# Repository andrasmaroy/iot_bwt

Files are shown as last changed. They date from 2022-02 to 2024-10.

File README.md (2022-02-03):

# iot_bwt

ESP32 based IoT device to monitor usage of a BWT water filter and report it to Home Assistant via MQTT with TLS and authentication.

## Components

This code is running on a [FireBeetle ESP32 v4.0](https://www.dfrobot.com/product-1590.html) and is connected to a YF-S201 flow sensor along with a no-name 1100mAh LiPo battery. Connect the pins of YF-S201 like this: red - 3.3V, black - GND, yellow - `D2`/`IO25`on the FireBeetle board and use the JST PH 2-Pin battery terminal already on the board for the battery.

On the FireBeetle to get battery monitoring on pin A0 to work R10 and R11 need to be shorted (these are 0R resistors in the schematic). Reference and schematic: https://www.dfrobot.com/forum/viewtopic.php?t=19292

Flashing the FireBeetle with Arduino IDE: set upload speed to 921600 and flash frequency to 80MHz.

## Dependencies

* [ESP32 board definitions](https://github.com/espressif/arduino-esp32/blob/master/docs/arduino-ide/boards_manager.md)
* [ArduinoJson](https://arduinojson.org/)
* [PubSubClient](https://github.com/knolleary/pubsubclient/)
* [ulpcc](https://github.com/jasonful/lcc)
* [ezTime](https://github.com/ropg/ezTime)

## Configuration

All relevant configuration values are in [config.h](config.h), fill in the necessary values to get the project working.

To be able to use secure MQTT connections the appropriate CA has to be added. The one in the code is Let's Encrypt's cross-signed intermediate CA, any pem format CA should work.
**Disclaimer:** I've only got this working got this working with directly the signing certificate, not with a complete certificate chain.

### Home Assistant

The way the code communicates with Home Assistant assumes that [MQTT Discovery](https://www.home-assistant.io/docs/mqtt/discovery/) is enabled and presents as two sensors to be used with a [Utility Meter](https://www.home-assistant.io/integrations/utility_meter/). See example of relevant configuration in [home-assistant.yaml](home-assistant.yaml)

## Acknowledgments

* Espessif's [ULP Pulse Counting Example](https://github.com/espressif/esp-idf/tree/master/examples/system/ulp)
* [C version](https://github.com/jasonful/lcc/blob/master/ulpcc/examples/pulse_cnt.c) of the above courtesy of [ulpcc](https://github.com/jasonful/lcc)

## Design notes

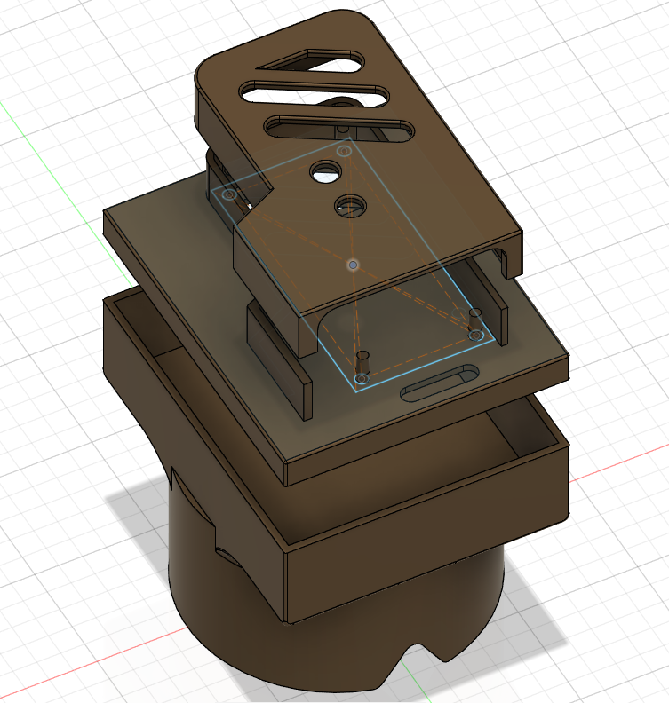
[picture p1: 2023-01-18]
case/Final.png

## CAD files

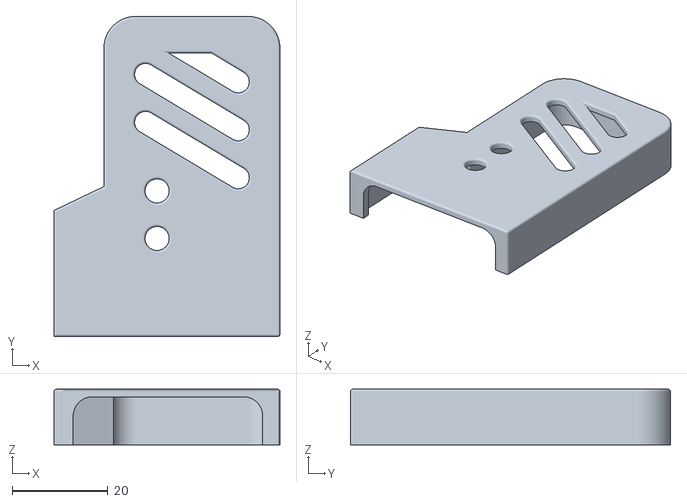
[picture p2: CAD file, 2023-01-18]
case/Controler top.stl
47.1 x 66.7 x 11.6

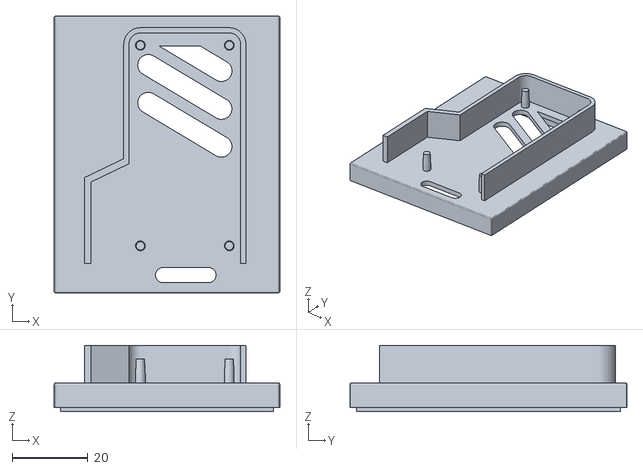
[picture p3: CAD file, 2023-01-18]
case/Battery top.stl
59.7 x 73.2 x 17.5

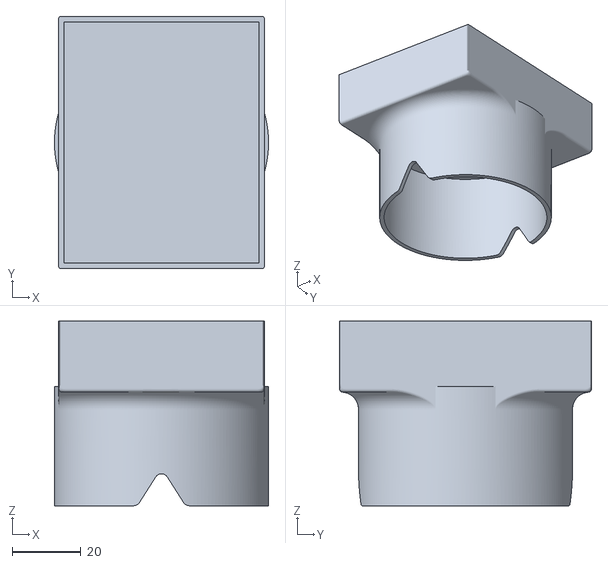
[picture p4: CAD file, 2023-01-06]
case/Base.stl
62.2 x 73.2 x 53.6

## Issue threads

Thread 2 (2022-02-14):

Design enclosure

andrasmaroy, 2022-02-14:
Should fit on top of the BWT filter (while still allowing a wall mount) and provides a firm connection for the flow sensor connector and exposes the USB port for charging.

Closed 2023-01-06.

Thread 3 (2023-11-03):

Report battery percentage while charging

andrasmaroy, 2023-11-03:
When charging the battery the current charge percentage should be reported actively since power is available. Reporting only the battery percentage without flow usage should work with Home Assistant, but needs testing. Otherwise reporting 0 should be fine.

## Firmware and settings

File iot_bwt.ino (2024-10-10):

#include <ArduinoJson.h>
#include <ezTime.h>
#include <PubSubClient.h>
#include <WiFiClientSecure.h>

#include <driver/rtc_io.h>
#include <esp32/ulp.h>
#include <nvs.h>
#include <nvs_flash.h>
#include <ulptool.h>

#include "config.h"
#include "ulp_main.h"

#define uS_TO_S_FACTOR 1000000ULL

extern const uint8_t ulp_main_bin_start[] asm("_binary_ulp_main_bin_start");
extern const uint8_t ulp_main_bin_end[]   asm("_binary_ulp_main_bin_end");

static void init_ulp_program(void);
static void update_pulse_count(void);

WiFiClientSecure wifiClient;
PubSubClient mqttClient(MQTT_URL, MQTT_PORT, wifiClient);

bool publish_config(const String& topic, const byte* bytes, size_t len) {
    Serial.print("Publishing message to '");
    Serial.print(topic);
    Serial.println("'");

    if (! mqttClient.beginPublish(topic.c_str(), len, true)) {
        Serial.println("Error beginning publish");
        return false;
    }
    if (len != mqttClient.write(bytes, len)) {
        Serial.println("Mismatch in written message length!");
        return false;
    }
    if (! mqttClient.endPublish()) {
        Serial.println("Error ending publish");
        return false;
    }
    return true;
}

bool publish_message(const String& topic, const String& msg) {
    Serial.print("Publishing message to '");
    Serial.print(topic);
    Serial.println("'");

    bool res = mqttClient.publish(topic.c_str(), msg.c_str(), true);
    for (uint8_t retries = 0; retries < MAX_RETRY_COUNT && ! res; retries++) {
        Serial.println("Error publishing message");
        Serial.println(" try again in 5 seconds");
        delay(RETRY_DELAY);
        res = mqttClient.publish(topic.c_str(), msg.c_str(), true);
    }
    return res;
}

bool announce_device() {
    Serial.println("Announcing devices");
    StaticJsonDocument<400> configuration;
    byte configBytes[400];
    size_t msgLen;
    uint8_t retries;

    // Flow sensor
    configuration["name"] = "BWT - Water";
    configuration["unit_of_measurement"] = "L";
    configuration["unique_id"] = "bwtwatersensor1";
    configuration["expire_after"] = 90000; // 25 hours
    configuration["state_topic"] = HASS_TOPIC_BASE + "/state";
    configuration["value_template"] = "{{ value_json.water}}";

    msgLen = measureJson(configuration);
    serializeJson(configuration, configBytes, msgLen + 1);

    bool res = publish_config(HASS_TOPIC_BASE + "W/config", configBytes, msgLen);
    for (uint8_t retries = 0; retries < MAX_RETRY_COUNT && ! res; retries++) {
        Serial.println(" try again in 5 seconds");
        delay(RETRY_DELAY);
        res = publish_config(HASS_TOPIC_BASE + "W/config", configBytes, msgLen);
    }
    if (!res) {
        return false;
    }
    serializeJsonPretty(configuration, Serial);
    Serial.println();

    // Battery sensor
    configuration["device_class"] = "battery";
    configuration["name"] = "BWT - Battery Level";
    configuration["unit_of_measurement"] = "%";
    configuration["unique_id"] = "bwtbatsensor1";
    configuration["expire_after"] = 172800; // 2 days
    configuration["state_topic"] = HASS_TOPIC_BASE + "/state";
    configuration["value_template"] = "{{ value_json.battery }}";

    msgLen = measureJson(configuration);
    serializeJson(configuration, configBytes, msgLen + 1);
    res = publish_config(HASS_TOPIC_BASE + "B/config", configBytes, msgLen);
    for (uint8_t retries = 0; retries < MAX_RETRY_COUNT && ! res; retries++) {
        Serial.println(" try again in 5 seconds");
        delay(RETRY_DELAY);
        res = publish_config(HASS_TOPIC_BASE + "B/config", configBytes, msgLen);
    }
    if (!res) {
        return false;
    }
    serializeJsonPretty(configuration, Serial);
    Serial.println();
    return true;
}

void sleep() {
    time_t wakeup_time = WAKEUP_FALLBACK;
    // Get time from NTP to calculate next wakeup time
    if (waitForSync(RETRY_DELAY)) {
      Timezone tz;
      tz.setPosix(TIMEZONE);
      wakeup_time = makeTime(WAKEUP_HOUR, WAKEUP_MINUTE, 0, tz.day() + 1, tz.month(), tz.year()) - tz.now();
    }

    Serial.println("Entering deep sleep\n\n");
    ESP_ERROR_CHECK(esp_sleep_enable_timer_wakeup(wakeup_time * uS_TO_S_FACTOR));
    esp_deep_sleep_start();
}

void setup() {
    //Initialize serial and wait for port to open:
    Serial.begin(115200);
    delay(100);

    esp_sleep_wakeup_cause_t cause = esp_sleep_get_wakeup_cause();
    if (cause != ESP_SLEEP_WAKEUP_TIMER) {
        printf("Not timed wakeup, initializing ULP\n");
        init_ulp_program();
    } else {
        printf("ULP wakeup, saving pulse count\n");
        update_pulse_count();
        Serial.print("Attempting to connect to SSID: ");
        Serial.println(WIFI_SSID);
        WiFi.begin(WIFI_SSID, WIFI_PSK);

        // attempt to connect to Wifi network:
        bool res = WiFi.status() == WL_CONNECTED;
        for (uint8_t retries = 0; retries < MAX_RETRY_COUNT && ! res; retries++) {
            Serial.print(".");
            delay(RETRY_DELAY);
            res = WiFi.status() == WL_CONNECTED;
        }
        if (!res) {
            Serial.println("WiFi connection failed, sleeping");
            sleep();
        }

        Serial.print("Connected to ");
        Serial.println(WIFI_SSID);
        Serial.print("IP address: ");
        Serial.println(WiFi.localIP());

        wifiClient.setCACert(ISRG_Root_X1);

        res = mqttClient.connected();
        for (uint8_t retries = 0; retries < MAX_RETRY_COUNT && ! res; retries++) {
            Serial.print("Attempting MQTT connection...");
            if (mqttClient.connect("iot_bwt", MQTT_USER, MQTT_PASSWORD)) {
                Serial.println("connected");
            } else {
                Serial.print("failed, rc=");
                Serial.print(mqttClient.state());
                Serial.println(" try again in 5 seconds");
                // Wait 5 seconds before retrying
                delay(RETRY_DELAY);
            }
            res = mqttClient.connected();
        }
        if (!res) {
            Serial.println("MQTT connection failed, sleeping");
            sleep();
        }

        if (!announce_device()) {
            Serial.println("Announcing devices failed, sleeping");
            sleep();
        }

        StaticJsonDocument<46> state;
        String stateStr;

        /*
         * Workaround Home Assistant' utility meter behaviour
         * It expects a monotonically increasing value and cumulates the
         * difference for each submission. To trick this into adding all the
         * submitted values straight up, we can send a 0 value before sending
         * the real one, this way the difference is always compared to 0, so
         * the correct value gets added.
         */
        state["battery"] = (uint8_t)((float)(analogRead(A0) - BATTERY_MIN) / (BATTERY_MAX - BATTERY_MIN) * 100);
        if (state["battery"] > 100) state["battery"] = 100;
        state["water"] = 0;
        stateStr = "";
        serializeJson(state, stateStr);
        res = publish_message(HASS_TOPIC_BASE + "/state", stateStr);
        serializeJsonPretty(state, Serial);
        Serial.println();

        if (res) {
            // Publish actual usage second
            const char* namespc = "pulsecnt";
            const char* count_key = "count";

            ESP_ERROR_CHECK( nvs_flash_init() );
            nvs_handle handle;
            ESP_ERROR_CHECK( nvs_open(namespc, NVS_READWRITE, &handle));
            uint32_t pulse_count = 0;
            esp_err_t err = nvs_get_u32(handle, count_key, &pulse_count);
            assert(err == ESP_OK || err == ESP_ERR_NVS_NOT_FOUND);

            state["water"] = (float)pulse_count / 400;
            stateStr = "";
            serializeJson(state, stateStr);
            if (publish_message(HASS_TOPIC_BASE + "/state", stateStr)) {
                ESP_ERROR_CHECK(nvs_set_u32(handle, count_key, 0));
                ESP_ERROR_CHECK(nvs_commit(handle));
            }
            serializeJsonPretty(state, Serial);
            Serial.println();

            nvs_close(handle);

            // Publish 0 usage again so that retained messages don't result in
            // false data when picked up.
            state["water"] = 0;
            stateStr = "";
            serializeJson(state, stateStr);
            res = publish_message(HASS_TOPIC_BASE + "/state", stateStr);
            serializeJsonPretty(state, Serial);
            Serial.println();
        }
    }

    sleep();
}

static void init_ulp_program(void) {
    esp_err_t err = ulp_load_binary(0, ulp_main_bin_start,
            (ulp_main_bin_end - ulp_main_bin_start) / sizeof(uint32_t));
    ESP_ERROR_CHECK(err);

    /* GPIO used for pulse counting. */
    gpio_num_t gpio_num = PIN_FLOW_SENSOR;
    int rtcio_num = PIN_RTC;
    assert(rtc_gpio_is_valid_gpio(gpio_num) && "GPIO used for pulse counting must be an RTC IO");

    /*
     * Initialize some variables used by ULP program.
     * Each 'ulp_xyz' variable corresponds to 'xyz' variable in the ULP program.
     * These variables are declared in an auto generated header file,
     * 'ulp_main.h', name of this file is defined in component.mk as ULP_APP_NAME.
     * These variables are located in RTC_SLOW_MEM and can be accessed both by the
     * ULP and the main CPUs.
     *
     * Note that the ULP reads only the lower 16 bits of these variables.
     */
    ulp_debounce_counter = 3;
    ulp_debounce_max_count = 3;
    ulp_next_edge = 0;
    ulp_io_number = rtcio_num; /* map from GPIO# to RTC_IO# */
    // ulp_edge_count_to_wake_up = 200;

    /* Initialize selected GPIO as RTC IO, enable input, disable pullup and pulldown */
    rtc_gpio_init(gpio_num);
    rtc_gpio_set_direction(gpio_num, RTC_GPIO_MODE_INPUT_ONLY);
    // rtc_gpio_pulldown_dis(gpio_num);
    rtc_gpio_pullup_dis(gpio_num);
    rtc_gpio_hold_en(gpio_num);

    /*
     * Disconnect GPIO12 and GPIO15 to remove current drain through
     * pullup/pulldown resistors.
     * GPIO12 may be pulled high to select flash voltage.
     */
    rtc_gpio_isolate(GPIO_NUM_12);
    rtc_gpio_isolate(GPIO_NUM_15);
    esp_deep_sleep_disable_rom_logging(); // suppress boot messages

    /*
     * Set ULP wake up period
     * Minimum pulse width has to be T * (ulp_debounce_counter + 1)
     * Maximum flow rate is about 6 L/min which corresponds to 50Hz
     * To be on the safe side consider double that
     * That means a wake up period that is able to detect 10ms pulses
     */
    ulp_set_wakeup_period(0, 10.0 / (ulp_debounce_counter + 1) * 1000);

    /* Start the program */
    err = ulp_run(&ulp_entry - RTC_SLOW_MEM);
    ESP_ERROR_CHECK(err);
}

static void update_pulse_count(void) {
    const char* namespc = "pulsecnt";
    const char* count_key = "count";

    ESP_ERROR_CHECK(nvs_flash_init());
    nvs_handle handle;
    ESP_ERROR_CHECK(nvs_open(namespc, NVS_READWRITE, &handle));
    uint32_t pulse_count = 0;
    esp_err_t err = nvs_get_u32(handle, count_key, &pulse_count);
    assert(err == ESP_OK || err == ESP_ERR_NVS_NOT_FOUND);
    printf("Read pulse count from NVS: %5d\n", pulse_count);

    /* ULP program counts signal edges, convert that to the number of pulses */
    uint32_t pulse_count_from_ulp = (ulp_edge_count & UINT16_MAX) / 2;
    /* In case of an odd number of edges, keep one until next time */
    ulp_edge_count = ulp_edge_count % 2;
    printf("Pulse count from ULP: %5d\n", pulse_count_from_ulp);

    /* Save the new pulse count to NVS */
    pulse_count += pulse_count_from_ulp;
    ESP_ERROR_CHECK(nvs_set_u32(handle, count_key, pulse_count));
    ESP_ERROR_CHECK(nvs_commit(handle));
    nvs_close(handle);
    printf("Wrote updated pulse count to NVS: %5d\n", pulse_count);
}

void loop() { }

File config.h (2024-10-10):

#ifndef CONFIG_H
#define CONFIG_H

// WiFi
#define WIFI_SSID ""
#define WIFI_PSK  ""

// MQTT
#define MQTT_URL      ""
#define MQTT_PORT     1883
#define MQTT_DEV      ""
#define MQTT_USER     ""
#define MQTT_PASSWORD ""

// Battery
#define BATTERY_MIN 1740
#define BATTERY_MAX 2320

// Flow sensor
#define FLOW_PULSE_PER_LITER 400
#define PIN_FLOW_SENSOR      GPIO_NUM_25
#define PIN_RTC              6  // RTC Pin number corresponding to GPIO 25

#define MAX_RETRY_COUNT 5
#define RETRY_DELAY 5000

#define WAKEUP_HOUR     23
#define WAKEUP_MINUTE   55
#define WAKEUP_FALLBACK 86400 // 1 day as fallback

#define TIMEZONE "CET-1CEST,M3.5.0,M10.5.0/3" // Europe/Budapest


const char* ISRG_Root_X1 = \
    "-----BEGIN CERTIFICATE-----\n" \
    "MIIFazCCA1OgAwIBAgIRAIIQz7DSQONZRGPgu2OCiwAwDQYJKoZIhvcNAQELBQAw\n" \
    "TzELMAkGA1UEBhMCVVMxKTAnBgNVBAoTIEludGVybmV0IFNlY3VyaXR5IFJlc2Vh\n" \
    "cmNoIEdyb3VwMRUwEwYDVQQDEwxJU1JHIFJvb3QgWDEwHhcNMTUwNjA0MTEwNDM4\n" \
    "WhcNMzUwNjA0MTEwNDM4WjBPMQswCQYDVQQGEwJVUzEpMCcGA1UEChMgSW50ZXJu\n" \
    "ZXQgU2VjdXJpdHkgUmVzZWFyY2ggR3JvdXAxFTATBgNVBAMTDElTUkcgUm9vdCBY\n" \
    "MTCCAiIwDQYJKoZIhvcNAQEBBQADggIPADCCAgoCggIBAK3oJHP0FDfzm54rVygc\n" \
    "h77ct984kIxuPOZXoHj3dcKi/vVqbvYATyjb3miGbESTtrFj/RQSa78f0uoxmyF+\n" \
    "0TM8ukj13Xnfs7j/EvEhmkvBioZxaUpmZmyPfjxwv60pIgbz5MDmgK7iS4+3mX6U\n" \
    "A5/TR5d8mUgjU+g4rk8Kb4Mu0UlXjIB0ttov0DiNewNwIRt18jA8+o+u3dpjq+sW\n" \
    "T8KOEUt+zwvo/7V3LvSye0rgTBIlDHCNAymg4VMk7BPZ7hm/ELNKjD+Jo2FR3qyH\n" \
    "B5T0Y3HsLuJvW5iB4YlcNHlsdu87kGJ55tukmi8mxdAQ4Q7e2RCOFvu396j3x+UC\n" \
    "B5iPNgiV5+I3lg02dZ77DnKxHZu8A/lJBdiB3QW0KtZB6awBdpUKD9jf1b0SHzUv\n" \
    "KBds0pjBqAlkd25HN7rOrFleaJ1/ctaJxQZBKT5ZPt0m9STJEadao0xAH0ahmbWn\n" \
    "OlFuhjuefXKnEgV4We0+UXgVCwOPjdAvBbI+e0ocS3MFEvzG6uBQE3xDk3SzynTn\n" \
    "jh8BCNAw1FtxNrQHusEwMFxIt4I7mKZ9YIqioymCzLq9gwQbooMDQaHWBfEbwrbw\n" \
    "qHyGO0aoSCqI3Haadr8faqU9GY/rOPNk3sgrDQoo//fb4hVC1CLQJ13hef4Y53CI\n" \
    "rU7m2Ys6xt0nUW7/vGT1M0NPAgMBAAGjQjBAMA4GA1UdDwEB/wQEAwIBBjAPBgNV\n" \
    "HRMBAf8EBTADAQH/MB0GA1UdDgQWBBR5tFnme7bl5AFzgAiIyBpY9umbbjANBgkq\n" \
    "hkiG9w0BAQsFAAOCAgEAVR9YqbyyqFDQDLHYGmkgJykIrGF1XIpu+ILlaS/V9lZL\n" \
    "ubhzEFnTIZd+50xx+7LSYK05qAvqFyFWhfFQDlnrzuBZ6brJFe+GnY+EgPbk6ZGQ\n" \
    "3BebYhtF8GaV0nxvwuo77x/Py9auJ/GpsMiu/X1+mvoiBOv/2X/qkSsisRcOj/KK\n" \
    "NFtY2PwByVS5uCbMiogziUwthDyC3+6WVwW6LLv3xLfHTjuCvjHIInNzktHCgKQ5\n" \
    "ORAzI4JMPJ+GslWYHb4phowim57iaztXOoJwTdwJx4nLCgdNbOhdjsnvzqvHu7Ur\n" \
    "TkXWStAmzOVyyghqpZXjFaH3pO3JLF+l+/+sKAIuvtd7u+Nxe5AW0wdeRlN8NwdC\n" \
    "jNPElpzVmbUq4JUagEiuTDkHzsxHpFKVK7q4+63SM1N95R1NbdWhscdCb+ZAJzVc\n" \
    "oyi3B43njTOQ5yOf+1CceWxG1bQVs5ZufpsMljq4Ui0/1lvh+wjChP4kqKOJ2qxq\n" \
    "4RgqsahDYVvTH9w7jXbyLeiNdd8XM2w9U/t7y0Ff/9yi0GE44Za4rF2LN9d11TPA\n" \
    "mRGunUHBcnWEvgJBQl9nJEiU0Zsnvgc/ubhPgXRR4Xq37Z0j4r7g1SgEEzwxA57d\n" \
    "emyPxgcYxn/eR44/KJ4EBs+lVDR3veyJm+kXQ99b21/+jh5Xos1AnX5iItreGCc=\n" \
    "-----END CERTIFICATE-----\n";

#endif  // CONFIG_H

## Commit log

2020-10-18 Add details about battery level monitoring
2020-10-31 Expire device after 25 hours instead of 2 days
2020-10-31 Fine tune battery measurements
2020-11-15 More battery value tuning
2021-04-09 Update readme with wiring details
2021-08-05 Remove availability topic from device configuration
2021-08-05 Retain MQTT messages
    Setting the retain flag for these messages is important, because when
    Home Assistant starts the device is missing, since it is from MQTT
    discovery[1]. If the message is retained then when Home Assistant
    subscribes again to the discovery topic it will receive the device
    configuration and registers it again correctly.
    [1] https://www.home-assistant.io/docs/mqtt/discovery/
    [iot_bwt.ino]
2021-09-03 Clamp battery percentage to 100
    If the voltage is read from the pin while charing the battery, then the calculated percentage might go over 100%. Because of this if should be clamped to the max value
2021-09-29 Send 0L usage after successfully publishing the actual usage
    Since messages are retained the last message in the state topic will
    contain the actual usage. This when combined with Home Assistant
    restarting the next day before the actual usage of the coming day
    published to set the usage for the day incorrectly to the same value as
    the day before.
    Publishing 0 after the actual usage won't change the calculation as for
    that a 0 value is already needed.
    [iot_bwt.ino]
2022-02-03 Implement waking up just before midnight
    Use NTP to fetch current time before going to deep sleep and use that to
    calculate the amount of time to sleep in order to wake up at the right
    time.
    If querying the NTP server fails fall back to just sleeping for a day.
    By setting the timezone with POSIX format we can avoid any network
    traffic other than actual NTP queries on 123/UDP.
    [config.h, iot_bwt.ino]
2023-01-06 Add 3D model for case
    fixes #2
    [Base.stl, Battery top.stl, Controler top.stl]
2023-01-18 Update case design
    There were issues with the microcontroller fitting in the case, this updates solves that problem.
    [Battery top.stl, Controler top.stl]
2024-10-10 Use ISRG Root CA instead of intermediate Let's Encrypt CA
    The intermediate CA is updated on a regular basis thus each time a new certificate is signed with a new CA this would need an update on the MCU. Using the CA one up in the chain alleviates this.
